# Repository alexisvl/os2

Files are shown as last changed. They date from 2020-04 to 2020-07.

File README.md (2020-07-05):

# OS-2

dope ass 90s under construction gif

This is my attempt at building an analog oscilloscope.

Bit of a self-indulgent project and I'm just posting it here so I don't hoard
it for myself. Nothing here is probably of use to anybody, and I have no plan
on making it in any way reproducible. License for all design files and
documentation is CC BY-NC-SA, note _non-commercial_. Any code is independently
licensed, typically GPL. If you want to spend a lot of money building something
mildly useful, feel free to build one.

## Specs

- At least 20 MHz bandwidth, maybe more
- Two to four channels
    - 1mV/div to 5V/div
    - AC, DC, GND coupling; 50 ohm or 1M termination
    - Switchable bandwidth limit per channel (if the overall bandwidth is high enough?)
- On-screen display for scale factors (raster scan)
- No software - ROM LUTs and GAL/PALs at most

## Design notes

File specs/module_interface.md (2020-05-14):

# OS-2 module interface

While the OS-2 does not utilize removable plugins, several system blocks are
implemented as self-contained modules. This document describes the interface
between them and the rest of the system.

## Power interface

Several power supplies are provided to modules, on the followings pins:

- GND (many pins, interspersed on connector)
- +55V - low current, analog rail
- +24V - high current, bulk unregulated rail
- +15V - medium current, quiet analog rail
- +12V - high current, general rail (relays, etc)
- +10.00V - low current (≤10mA), precise reference rail
- +5V - high current, general rali
- -15V - medium current, quiet analog rail
- -55V - low current, analog rail

## On-screen display (OSD) interface

(See also: [On-screen display](./on_screen_display.md))

The following pins go to all vertical, horizontal, and caption modules to
implement the on-screen display:

| Pin | Direction | Function |
|---|---|---|
| FIELDSELECT | to mod | Asserts when module should drive CHARn |
| POS0 – POS2 | to mod | Selects a character position (0-7) |
| CHAR0 – CHAR6 | from mod  | Open coll; drives character bits on SELECT |
| CHARINTEN | from mod  | Open coll active low; intensifies character |

From the moment FIELDSELECT or POSn changes, a module has 10µs to respond with
the next character code. When FIELDSELECT is not asserted, the module should not
drive the CHARn lines.

Because the OSD interface prefetches one character ahead of the display module,
the normal INTEN signal cannot be used to intensify the character being
requested. Use CHARINTEN instead; this is latched for use in the next cycle.

## Signal interfaces

The signal interface is a differential current-sink interface. It is biased to
a common-mode voltage by the receiver and terminated into 160 ohms differential.

Signal level is 0.5V per division, with the center of the display at (ideally)
0V. Because the display measures 10 divisions by 8 divisions, the voltage to
reach the display edges is ±2.5V (horizontally) or ±2.0V (vertically), or
±16.6mA (horizontally) or ±13.3mA (vertically) current-mode. Common-mode sink
current may be up to 30mA.

Common-mode termination voltages vary to simplify circuit implementation. They
are as follows:

- Primary SIG/TSIG signals from vertical modules terminate into +4.5V. Trigger
    level output LEVEL is included here (it behaves as an extra vertical
    channel) as is OSDV.
- Primary horizontal signals SIG, TSIG terminate into +9V, allowing them to
    be easily developed from the prior +4.5V signals.
- Display switch output SIG terminates into +9V.

An example termination circuit and transmitter for 16.6mApp. To use at 13.3mApp
with the same input voltage, change the 120 ohm gain resistor to 180 ohms. Gain
values are approximate; for applications requiring accurate gain a gain trimpot
is suggested.

```
                   |       |
                   C       C
Vcm + 0.65V ------B-------B
                   E       E
                   |       |
        Vcm --[68]-+       +-[68]-- Vcm
                   |       |      
                   |       |
                   |       |
                   |       |
                   .inputs .
                   .       .
                   backplane   
                   .       .
                   .outputs.
                   |       |
                   +-[150]-+
                   |       |
                   C       C
single:  2Vpp ----B         B---- gnd
diff:    1Vpp      E       E      1Vpp 180°
                   |       |
                   +-[120]-+
                   |       |
                 [1 k]   [1 k]
                   |       |
                 -15V    -15V
```

### Vertical module

User IO:
- BNC input with probe sense ring
- Rotary encoder to select scale multipliers, LEDs to display
- Rotary encoder to select V/div
- Vernier pot and switch
- AC-GND-DC-GND-50 slider
- Invert slider
- ADD 1+2 or 3+4 slider on odd-numbered modules

Trigger signals are buffered duplicates of the primary signals.

| Pin | Direction | Function | Mode |
|---|---|---|---|
| SIG+ | from mod  | Primary signal, +ve | Differential, +4.5Vcm |
| SIG- | from mod  | Primary signal, -ve | Differential, +4.5Vcm |
| TSIG+ | from mod  | Trigger signal, +ve | Differential, +4.5Vcm |
| TSIG- | from mod  | Trigger signal, -ve | Differential, +4.5Vcm |
| INTEN | from mod  | Logic, assert to intensify | Open-coll active low 5V |
| BLANK | from mod  | Logic, assert to blank | Open-cool active low 5V |
| ACTIVE | to mod | Asserts when displaying | 5V CMOS |

ACTIVE is asserted by the display sequencer whenever this module's output is
currently being displayed. It should gate the INTEN signal, such that this
module will not drive INTEN while other modules are active.

### Trigger module

User IO:
- BNC external trigger
- Slider to select source: INT-EXT-LINE
- Rotary encoder to select internal source: CH1-CH2-CH3-CH4-ALL, LEDs to display
- Level pot
- Level slider: rising-falling

| Pin | Direction | Function | Mode |
|---|---|---|---|
| TSIG1+ | to mod | Trigger signal, +ve | Differential, +4.5Vcm |
| TSIG1- | to mod | Trigger signal, -ve | Differential, +4.5Vcm |
| TSIG2+ | to mod | Trigger signal, +ve | Differential, +4.5Vcm |
| TSIG2- | to mod | Trigger signal, -ve | Differential, +4.5Vcm |
| TSIG3+ | to mod | Trigger signal, +ve | Differential, +4.5Vcm |
| TSIG3- | to mod | Trigger signal, -ve | Differential, +4.5Vcm |
| TSIG4+ | to mod | Trigger signal, +ve | Differential, +4.5Vcm |
| TSIG4- | to mod | Trigger signal, -ve | Differential, +4.5Vcm |
| DONE | to mod | Sweep is complete | 5V CMOS |
| SWEEP | from mod  | Sweep gate | 5V CMOS |
| INHIBIT | to mod | Blocks trigger | Open-coll active low 5V |
| LEVEL+ | from mod  | DC trigger level, +ve | Differential, +4.5Vcm |
| LEVEL- | from mod  | DC trigger level, -ve | Differential, +4.5Vcm |
| LINE | to mod | Line trigger signal | 5V CMOS |
| SEL0-2 | to mod | Pre-decode OSD select | 5V CMOS |
| LVLEN | from mod  | Trigger level auto en | 5V CMOS |

LEVEL signals use the same specifications as general signals but may be
unterminated. These are used to allow the OSD module to visualize the
trigger onscreen.

SELn lines from the OSD module are connected to the trigger to allow it to
insert trigger symbols into the relevant OSD space.

LVLEN will be driven high for a second or two whenever the level pot is moved
(perhaps also when other controls move) to flash the trigger level on screen
when the selector on the display switch module is set to AUTO.

### Horizontal/sweep module

| Pin | Direction | Function | Mode |
|---|---|---|---|
| SWEEP | to mod | Sweep gate | 5V CMOS |
| DONE | from mod  | Sweep is complete | 5V CMOS |
| CH2+ | to mod | Ch2 for X/Y mode (+ve) | Differential, +4.5Vcm unterm  |
| CH2- | to mod | Ch2 for X/Y mode (-ve) | Differential, +4.5Vcm unterm  |
| OSDH+ | to mod | Horiz OSD scan, +ve | Differential, +4.5Vcm |
| OSDH- | to mod | Horiz OSD scan, -ve | Differential, +4.5Vcm |
| SIG+ | from mod  | Primary signal, +ve | Differential, +9.0Vcm |
| SIG- | from mod  | Primary signal, -ve | Differential, +9.0Vcm |
| TSIG+ | from mod  | Secondary signal, +ve | Differential, +9.0Vcm |
| TSIG- | from mod  | Secondary signal, -ve | Differential, +9.0Vcm |

TSIG is repurposed for rear panel ramp output, if used.

CH2 is an unterminated input bussed with TSIG2 on the trigger module, used to
deliver Ch 2 for use as the horizontal axis in X/Y mode.

SWEEP asserts for the duration of the sweep, and this module will assert DONE
when the sweep terminates; the trigger module may then begin counting its
holdoff and then re-arm.

OSDSIG lines are always summed into SIG but never into TSIG. When idle, the OSD
module will leave them at zero.

### Display sequencer module

User controls:
- Enable Ch1/Ch2/Ch3/Ch4
- Alt/Chop
- OSD on/off
- Trigger level display slider: OFF-AUTO-ON

| Pin | Direction | Function | Mode |
|---|---|---|---|
| SIG1+ | to mod | Signal input, +ve | Differential, +4.5Vcm |
| SIG1- | to mod | Signal input, -ve | Differential, +4.5Vcm |
| SIG2+ | to mod | Signal input, +ve | Differential, +4.5Vcm |
| SIG2- | to mod | Signal input, -ve | Differential, +4.5Vcm |
| SIG3+ | to mod | Signal input, +ve | Differential, +4.5Vcm |
| SIG3- | to mod | Signal input, -ve | Differential, +4.5Vcm |
| SIG4+ | to mod | Signal input, +ve | Differential, +4.5Vcm |
| SIG4- | to mod | Signal input, -ve | Differential, +4.5Vcm |
| OSDV+ | to mod | OSD scan input, +ve | Differential, +4.5Vcm |
| OSDV- | to mod | OSD scan input, -ve | Differential, +4.5Vcm |
| LEVEL+ | to mod | Trigger level input, +ve | Differential, +4.5Vcm |
| LEVEL- | to mod | Trigger level input, -ve | Differential, +4.5Vcm |
| OSDSEL | from mod  | Asserts when OSD selected | 5V CMOS |
| OSDDONE | to mod | Asserted when OSD completes | 5V CMOS |
| SWEEP | to mod | Sweep gate | 5V CMOS |
| DONE | to mod | Sweep is done | 5V CMOS |
| INHIBIT | from mod  | Trigger inhibit | Open-coll active low 5V |
| SIG+ | from mod  | Vertical signal out, +ve | Differential, +9.0Vcm |
| SIG- | from mod  | Vertical signal out, -ve | Differential, +9.0Vcm |
| TSIG+ | from mod  | Secondary signal out, +ve | Differential, +9.0Vcm |
| TSIG- | from mod  | Secondary signal out, -ve | Differential, +9.0Vcm |
| ADD12 | to mod | Asserts to sum ch1+ch2 | 5V CMOS |
| ADD34 | to mod | Asserts to sum ch3+ch4 | 5V CMOS |
| ALTINTEN  | from mod  | Selects alternate (OSD) inten | 5V CMOS |
| LVLEN | to mod | Trigger level auto enable | 5V CMOS |
| ACTIVE2-0 | from mod  | Active module indicators | 5V CMOS

LEVEL is not a critical signal; it should be routed on two of the SSn lines in the
general pinout.

ACTIVEn is decoded into a one-hot signal on the backplane. It indicates which of
the modules is currently being displayed, if any.

### OSD module

Rear-facing module with no user IOs.

| Pin | Direction | Function | Mode |
|---|---|---|---|
| CHAR0-5 | to mod | Character bus | Open-coll active low 5V |
| POS0-2 | from mod  | Position select bus | 5V CMOS |
| SEL0-2 | from mod  | Source enable lines | 5V CMOS |
| OSDSEL | to mod | Asserted to start OSD scan | 5V CMOS |
| OSDDONE | from mod  | Asserts when finished | 5V CMOS |
| HSCAN+ | from mod  | Horizontal scan, +ve | Differential, +4.5Vcm |
| HSCAN- | from mod  | Horizontal scan, -ve | Differential, +4.5Vcm |
| VSCAN+ | from mod  | Vertical scan, +ve | Differential, +4.5Vcm |
| VSCAN+ | from mod  | Vertical scan, -ve | Differential, +4.5Vcm |
| BEAMINHIB | from mod  | Asserts to inhibit beam | Open-coll active low 5V |

SELn are binary outputs; these are decoded to individual enable lines on the
backplane.

### Deflection amplifier module

User IO:
    - BNC jack with 1V/div output

| Pin | Direction | Function | Mode |
|---|---|---|---|
| SIG+ | to mod | Signal to display | Differential, +9.0Vcm |
| SIG- | to mod | Signal to display | Differential, +9.0Vcm |

### Cathode control module

Front-facing module with controls:

- Brightness, main
- Brightness, OSD
- Focus
- Astig
- Rotation

| Pin | Direction | Function | Mode |
|---|---|---|---|
| INTEN | to mod | Asserts to intensify beam | Open-coll active low 5V |
| INHIB | to mod | Inhibits beam (overrides INTEN) | Open-coll active low 5V |
| ALTINTEN  | to mod | Selects alternate (OSD) intensity | 5V CMOS

# General pinout

The same pinout is allocated different variant IOs depending on the module.

| Pin (C) | Function | Pin (B) | Function | Pin (A) | Function |
|---|---|---|---|---|---|
| C1 | g | B1 | g | A1 | g |
| C2 | SIG+ | B2 | g | A2 | TSIG+ |
| C3 | SIG- | B3 | g | A3 | TSIG- |
| C4 | g | B4 | g | A4 | g |
| C5 | IN1+ | B5 | g | A5 | SS0 |
| C6 | IN1- | B6 | g | A6 | SS1 |
| C7 | g | B7 | IN2+ | A7 | g |
| C8 | g | B8 | IN2- | A8 | g |
| C9 | IN3+ | B9 | g | A9 | SS2 |
| C10 | IN3- | B10 | g | A10 | SS3 |
| C11 | g | B11 | IN4+ | A11 | g |
| C12 | g | B12 | IN4- | A12 | g |
| C13 | IN5+ | B13 | g | A13 | SS4 |
| C14 | IN5- | B14 | g | A14 | SS5 |
| C15 | g | B15 | g | A15 | g |
| C16 | SA0 | B16 | SA1 | A16 | SA2 |
| C17 | SA3 | B17 | SA4 | A17 | g |
| C18 | SA5 | B18 | SA6 | A18 | SA7 |
| C19 | g | B19 | SA8 | A19 | SA9 |
| C20 | SA10 | B20 | g | A20 | SA11 |
| C21 | SA12 | B21 | SA13 | A21 | SA14 |
| C22 | SA15 | B22 | CHAR0 | A22 | CHAR1 |
| C23 | CHAR2 | B23 | CHAR3 | A23 | CHAR4 |
| C24 | CHAR5 | B24 | CHAR6 | A24 | CHARINTEN |
| C25 | POS0 | B25 | POS1 | A25 | POS2 |
| C26 | FIELDSELECT | B26 | g | A26 | +24V |
| C27 | g | B27 | +55V | A27 | +24V |
| C28 | g | B28 | +15V | A28 | +12V |
| C29 | +10.00V | B29 | g | A29 | +12V |
| C30 | g | B30 | g | A30 | +5V |
| C31 | -55V | B31 | -15V | A31 | +5V |
| C32 | g | B32 | g | A32 | g |

- SSn lines are "sweep synchronous". They are located in places where toggling
during a sweep could impose noise on the display, so they should only toggle
between sweeps. Example signals to allocate here are SWEEP, DONE.

- SAn lines are "sweep asynchronous". They are separated well from the analog
signal pins, and may toggle during sweep. These are generally used for all logic
signals not otherwise allocated to SSn.

- POSn, CHARn are the OSD IO lines bussed to all modules.

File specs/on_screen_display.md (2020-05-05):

# OS-2 on-screen display

## Display layout

The display has several areas where on-screen display content is overlayed with
the primary signal display:

```
VERT1   VERT2   VERT3   VERT4

>------- trig  level -------<

DESC1DESC2DESC3         HORIZ
```

All text fields are eight spaces long.

- `VERT1` through `VERT4`: each is "owned" by a different vertical channel
module. It typically displays a scale factor (like "5V") as well as one
of a few icons (a sine wave sign to indicate AC coupling, a ground symbol
for ground coupling, a Tek-style halfwidth BW for bandwidth limiting,
trigger indicators, an ohm sign for 50-ohm termination, an alert sign
for termination overheat or other critical conditions, and a transient
"IDENT" indication when a probe identifier is activated).

- `DESC1` to `DESC3` are arranged so they flow together into a single field,
and exist so that an optional captioning plugin may be used to write user-
specified labels onto the display.

- `HORIZ` displays a horizontal scale factor (like "50µs") and alternative
trigger source icons ("AU" for auto triggering, "LN" for line triggering)
that are not associated with a vertical channel.

- "Trig level" is a dashed line that can be optionally drawn across the display
at the selected trigger point. (Suggested dashed-line implementation: 555
timer, astable, reset line driven by sweep gate. This will reset it on every
sweep so the dashes line up)

All vertical channels should emit a space (0x3F, no lines asserted) for
position 0. The trigger module will insert trigger level symbols on the
relevant channel during the scan sequence.

## Character encoding

The OS-2 character encoding is six bits wide, and is defined as follows:

| Code  | Character |
|---|---|
| 0x00  | 0 |
| 0x01  | 1 |
| 0x02  | 2 |
| 0x03  | 3 |
| 0x04  | 4 |
| 0x05  | 5 |
| 0x06  | 6 |
| 0x07  | 7 |
| 0x08  | 8 |
| 0x09  | 9 |
| 0x0A  | . |
| 0x0B  | < |
| 0x0C  | > |
| 0x0D  | / |
| 0x0E  | - |
| 0x0F  | + |
| 0x10  | ∿ (sine wave) |
| 0x11  | Ω |
| 0x12  | ground symbol |
| 0x13  | BW (Tek style, combined single width) |
| 0x14  | LN (a la BW, for "LINE") |
| 0x15  | AU (a la BW, for "AUTO") |
| 0x16  | rising edge |
| 0x17  | falling edge |
| 0x18  | both edges |
| 0x19  | alert sign |
| 0x1A  | A |
| 0x1B  | B |
| 0x1C  | C |
| 0x1D  | D |
| 0x1E  | E |
| 0x1F  | F |
| 0x20  | G |
| 0x21  | H |
| 0x22  | I |
| 0x23  | J |
| 0x24  | K |
| 0x25  | L |
| 0x26  | M |
| 0x27  | N |
| 0x28  | O |
| 0x29  | P |
| 0x2A  | Q |
| 0x2B  | R |
| 0x2C  | S |
| 0x2D  | T |
| 0x2E  | U |
| 0x2F  | V |
| 0x30  | W |
| 0x31  | X |
| 0x32  | Y |
| 0x33  | Z |
| 0x34  | k |
| 0x35  | m |
| 0x36  | µ |
| 0x37  | n |
| 0x38  | p |
| 0x39  | s |
| 0x3A  | ° |
| 0x3B  | ? |
| 0x3C  | ♥ |
| 0x3D  | dither block |
| 0x3E  | full block |
| 0x3F  | space |

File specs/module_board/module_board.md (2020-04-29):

# Module board design

The module board format is inspired by (but not directly compatible with)
Eurocard. Overall dimensions are 160 by 100 mm, with a 64-pin DIN 41612
connector at the rear end, and a faceplate at the front end for connectors
and printed legends. The PCB layout file accompanying this document shall
serve as the specification for the format.

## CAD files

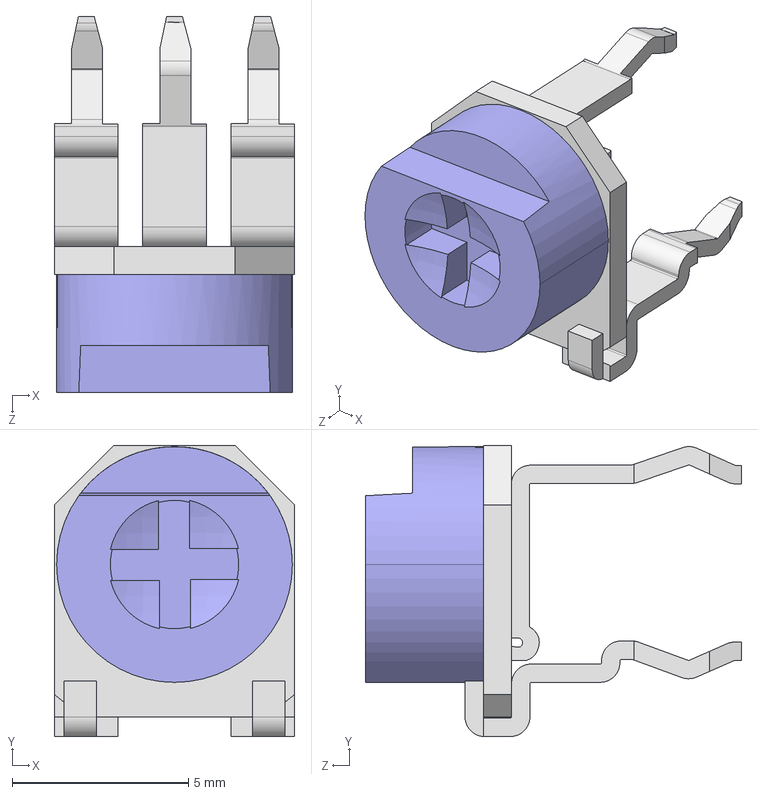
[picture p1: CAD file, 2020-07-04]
sch/gfx/User Library-Trimmer, 3306F-1.STEP
6.81 x 8.25 x 10.7 mm

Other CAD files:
mech/chassis.dxf

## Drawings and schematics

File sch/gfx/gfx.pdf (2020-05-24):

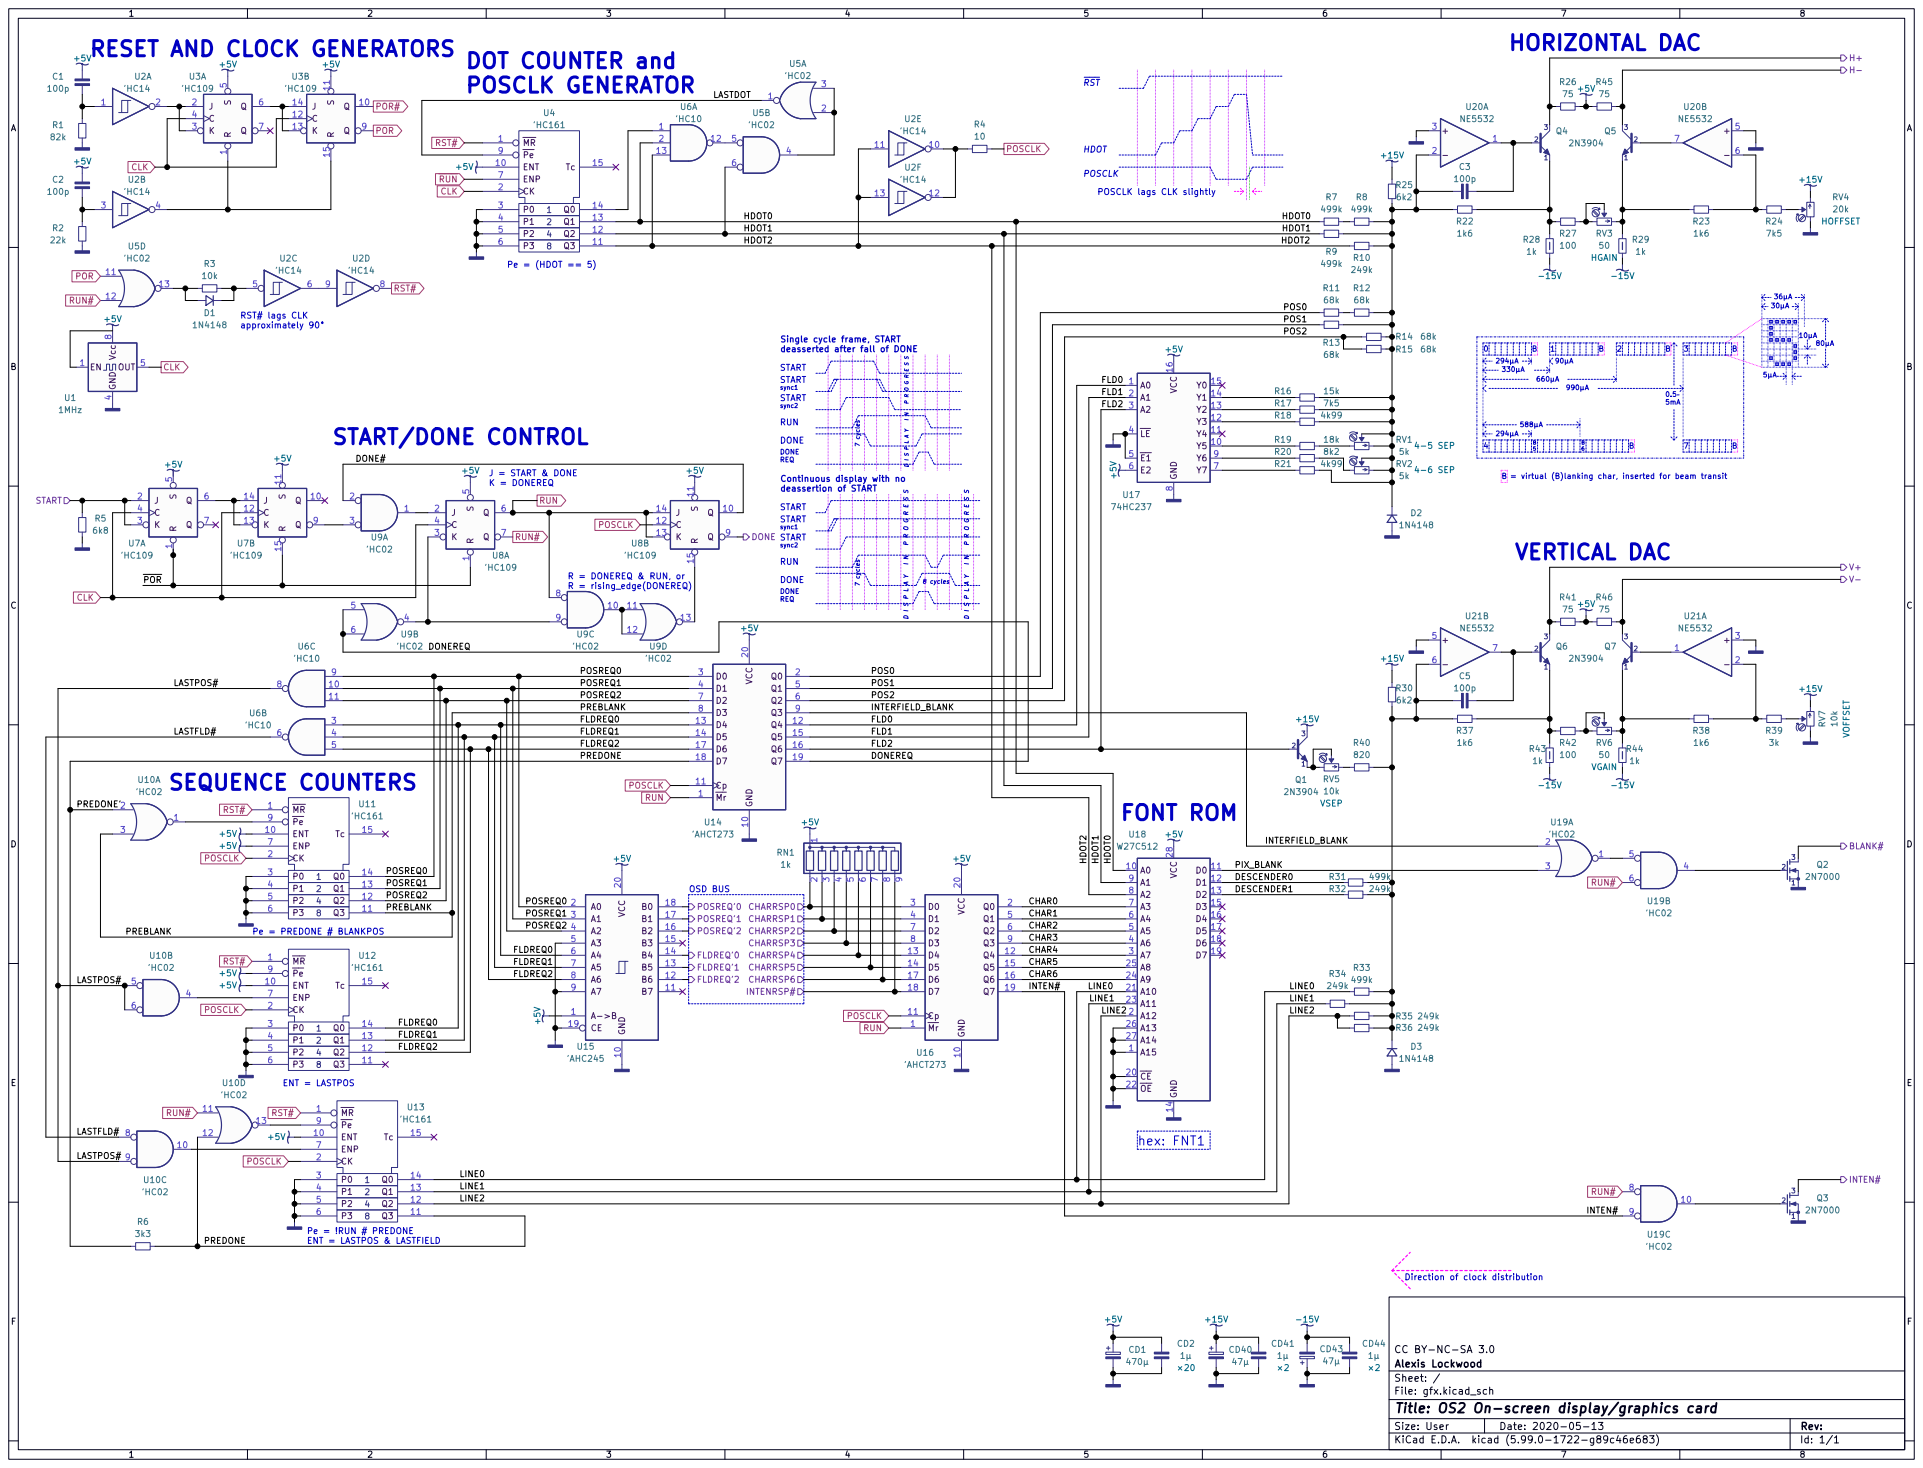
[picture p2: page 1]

5mA Pe = PREDONE # BLANKPOS RESET AND CLOCK GENERATORS DOT COUNTER and

POSCLK lags CLK slightly

Single cycle frame, START
80µA START
sync1 START

294µA R = DONEREQ & RUN, or R = rising_edge(DONEREQ)

sync2 DONE
DONE REQ Continuous display with no

Direction of clock distribution

File: gfx.kicad_sch Sheet: / Alexis Lockwood CC BY-NC-SA 3.0

Id: 1/1 Title: OS2 On-screen display/graphics card

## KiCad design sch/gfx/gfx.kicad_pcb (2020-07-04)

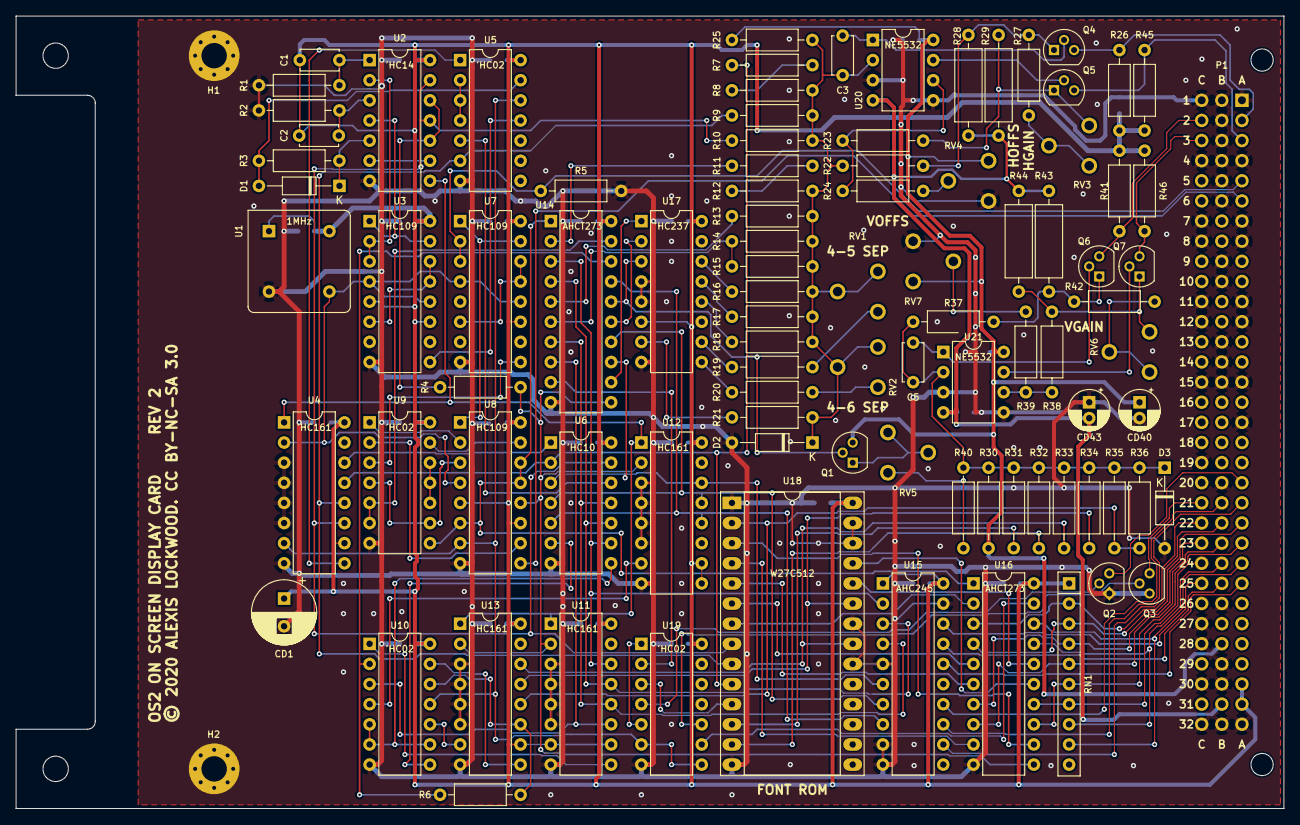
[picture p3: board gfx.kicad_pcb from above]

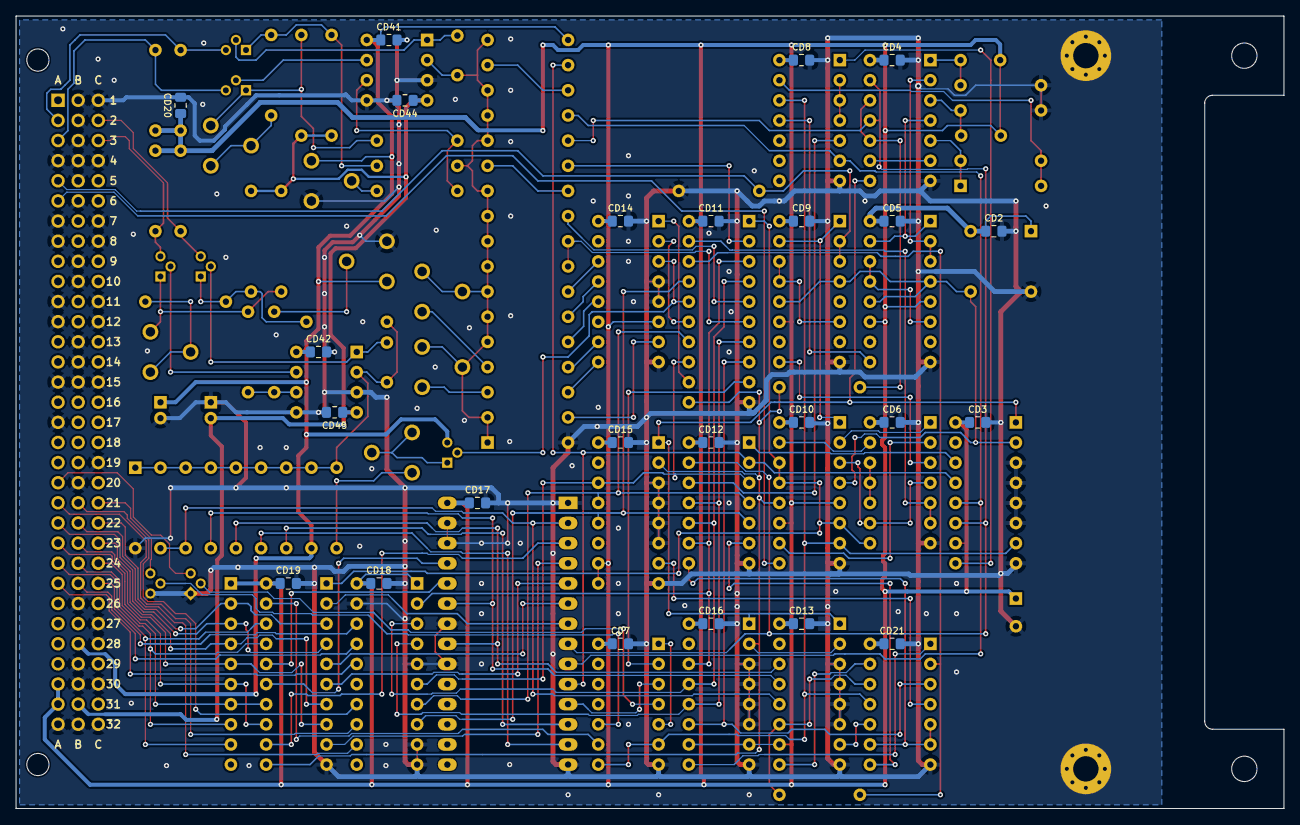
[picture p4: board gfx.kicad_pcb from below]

Board: 2 copper layers, 160.0 x 100.0 mm, 119 parts (24 on the bottom side), 124 nets.

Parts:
C1, C2, C3, C5: 100p; C_Disc_D4.7mm_W2.5mm_P5.00mm
CD1: 470µ; CP_Radial_D8.0mm_P3.50mm
CD2, CD3, CD4, CD5, CD6, CD7, CD8, CD9, CD10, CD11, CD12, CD13, CD14, CD15, CD16, CD17, CD18, CD19, CD20, CD21, CD41, CD42, CD44, CD45: 1µ; C_0805_2012Metric_Pad1.15x1.40mm_HandSolder
CD40, CD43: 47µ; CP_Radial_D5.0mm_P2.00mm
D1, D2, D3: 1N4148; D_DO-35_SOD27_P10.16mm_Horizontal
H1, H2: HOLE; MountingHole_3.2mm_M3_Pad_Via
P1: DIN41612_M_3x32; DIN41612_B_3x32_Horizontal
Q1, Q4, Q5, Q6, Q7: 2N3904; TO-92
Q2, Q3: 2N7000; TO-92
R1: 82k; R_Axial_DIN0207_L6.3mm_D2.5mm_P10.16mm_Horizontal
R2: 22k; R_Axial_DIN0207_L6.3mm_D2.5mm_P10.16mm_Horizontal
R3: 10k; R_Axial_DIN0207_L6.3mm_D2.5mm_P10.16mm_Horizontal
R4: 10; R_Axial_DIN0207_L6.3mm_D2.5mm_P10.16mm_Horizontal
R5: 6k8; R_Axial_DIN0207_L6.3mm_D2.5mm_P10.16mm_Horizontal
R6: 3k3; R_Axial_DIN0207_L6.3mm_D2.5mm_P10.16mm_Horizontal
R7, R8, R9, R31, R33: 499k; R_Axial_DIN0207_L6.3mm_D2.5mm_P10.16mm_Horizontal
R10, R32, R34, R35, R36: 249k; R_Axial_DIN0207_L6.3mm_D2.5mm_P10.16mm_Horizontal
R11, R12, R13, R14, R15: 68k; R_Axial_DIN0207_L6.3mm_D2.5mm_P10.16mm_Horizontal
R16: 15k; R_Axial_DIN0207_L6.3mm_D2.5mm_P10.16mm_Horizontal
R17, R24: 7k5; R_Axial_DIN0207_L6.3mm_D2.5mm_P10.16mm_Horizontal
R18, R21: 4k99; R_Axial_DIN0207_L6.3mm_D2.5mm_P10.16mm_Horizontal
R19: 18k; R_Axial_DIN0207_L6.3mm_D2.5mm_P10.16mm_Horizontal
R20: 8k2; R_Axial_DIN0207_L6.3mm_D2.5mm_P10.16mm_Horizontal
R22, R23, R37, R38: 1k6; R_Axial_DIN0207_L6.3mm_D2.5mm_P10.16mm_Horizontal
R25, R30: 6k2; R_Axial_DIN0207_L6.3mm_D2.5mm_P10.16mm_Horizontal
R26, R41, R45, R46: 75; R_Axial_DIN0207_L6.3mm_D2.5mm_P10.16mm_Horizontal
R27, R42: 100; R_Axial_DIN0207_L6.3mm_D2.5mm_P10.16mm_Horizontal
R28, R29, R43, R44: 1k; R_Axial_DIN0309_L9.0mm_D3.2mm_P12.70mm_Horizontal
R39: 3k; R_Axial_DIN0207_L6.3mm_D2.5mm_P10.16mm_Horizontal
R40: 820; R_Axial_DIN0207_L6.3mm_D2.5mm_P10.16mm_Horizontal
RN1: 1k; R_Array_SIP10
RV1, RV2: 5k; stock_pot
RV3, RV6: 50; stock_pot
RV4: 20k; stock_pot
RV5, RV7: 10k; stock_pot
U1: 1MHz; Oscillator_DIP-8
U2: 'HC14; DIP-14_W7.62mm
U3, U7, U8: 'HC109; DIP-16_W7.62mm
U4, U11, U12, U13: 'HC161; DIP-16_W7.62mm
U5, U9, U10, U19: 'HC02; DIP-14_W7.62mm
U6: 'HC10; DIP-14_W7.62mm
U14, U16: 'AHCT273; DIP-20_W7.62mm
U15: 'AHC245; DIP-20_W7.62mm
U17: 'HC237; DIP-16_W7.62mm
U18: W27C512; DIP-28_W15.24mm_Socket_LongPads
U20, U21: NE5532; DIP-8_W7.62mm

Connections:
+15V: CD40.1, CD41.1, CD42.1, P1.B28, Q1.3 (C), R25.2, R30.2, RV4.3, RV7.3, U20.8 (V+), U21.8 (V+)
-15V: CD43.2, CD44.1, CD45.1, P1.B31, R28.1, R29.1, R43.1, R44.1, U20.4 (V-), U21.4 (V-)
/CHAR0: U16.2 (Q0), U18.7 (A3)
/CHAR1: U16.5 (Q1), U18.6 (A4)
/CHAR2: U16.6 (Q2), U18.5 (A5)
/CHAR3: U16.9 (Q3), U18.4 (A6)
/CHAR4: U16.12 (Q4), U18.3 (A7)
/CHAR5: U16.15 (Q5), U18.25 (A8)
/CHAR6: U16.16 (Q6), U18.24 (A9)
/DESCENDER0: R31.2, U18.12 (D1)
/DESCENDER1: R32.2, U18.13 (D2)
/DONE#: U8.10 (Q), U9.2
/DONEREQ: U9.5, U9.6, U14.19 (Q7)
/FLD0: U14.12 (Q4), U17.1 (A0)
/FLD1: U14.15 (Q5), U17.2 (A1)
/FLD2: Q1.2 (B), U14.16 (Q6), U17.3 (A2)
/FLDREQ0: U6.3, U12.14 (Q0), U14.13 (D4), U15.6 (A4)
/FLDREQ1: U6.4, U12.13 (Q1), U14.14 (D5), U15.7 (A5)
/FLDREQ2: U6.5, U12.12 (Q2), U14.17 (D6), U15.8 (A6)
/HDOT0: R7.2, U4.13 (Q1), U6.2, U18.10 (A0)
/HDOT1: R9.2, U4.12 (Q2), U5.6, U18.9 (A1)
/HDOT2: R10.2, U2.11, U2.13, U4.11 (Q3), U6.13, U18.8 (A2)
/INTEN#: U16.19 (Q7), U19.9
/INTERFIELD_BLANK: U14.9 (Q3), U19.2
/LASTDOT: U4.9 (~Pe), U5.1
/LASTFLD#: U6.6, U10.8
/LASTPOS#: U6.8, U10.5, U10.6, U10.9
/LINE0: R33.2, U13.14 (Q0), U18.21 (A10)
/LINE1: R34.2, U13.13 (Q1), U18.23 (A11)
/LINE2: R35.2, R36.2, U13.12 (Q2), U18.2 (A12)
/PIX_BLANK: U18.11 (D0), U19.3
/POS0: R11.2, U14.2 (Q0)
/POS1: R13.2, U14.5 (Q1)
/POS2: R14.2, R15.2, U14.6 (Q2)
/POSREQ0: U6.9, U11.14 (Q0), U14.3 (D0), U15.2 (A0)
/POSREQ1: U6.10, U11.13 (Q1), U14.4 (D1), U15.3 (A1)
/POSREQ2: U6.11, U11.12 (Q2), U14.7 (D2), U15.4 (A2)
/PREBLANK: U10.3, U11.11 (Q3), U14.8 (D3)
/PREDONE: R6.2, U10.12, U13.11 (Q3)
/PREDONE': R6.1, U10.2, U14.18 (D7)
/~POR: U7.1 (R), U7.15 (R), U8.1 (R)
A2: P1.A2, Q4.3 (C), R26.1
A3: P1.A3, Q5.3 (C), R45.2
A5: P1.A5, R5.2, U7.2 (J), U7.3 (K)
A6: P1.A6, U8.9 (Q)
A20: P1.A20, Q2.3 (D)
A21: P1.A21, U15.13 (B5)
A22: P1.A22, RN1.3 (R2), U16.4 (D1)
A23: P1.A23, RN1.6 (R5), U16.13 (D4)
A24: P1.A24, RN1.9 (R8), U16.18 (D7)
A25: P1.A25, U15.16 (B2)
B21: P1.B21, U15.14 (B4)
B22: P1.B22, RN1.2 (R1), U16.3 (D0)
B23: P1.B23, RN1.5 (R4), U16.8 (D3)
B24: P1.B24, RN1.8 (R7), U16.17 (D6)
B25: P1.B25, U15.17 (B1)
C2: P1.C2, Q6.3 (C), R41.1
C3: P1.C3, Q7.3 (C), R46.2
C21: P1.C21, Q3.3 (D)
C22: P1.C22, U15.12 (B6)
C23: P1.C23, RN1.4 (R3), U16.7 (D2)
C24: P1.C24, RN1.7 (R6), U16.14 (D5)
C25: P1.C25, U15.18 (B0)
CLK: U1.5 (OUT), U3.4 (C), U3.12 (C), U4.2 (CK), U7.4 (C), U7.12 (C), U8.4 (C)
GND: CD1.2, CD2.2, CD3.2, CD4.2, CD5.2, CD6.2, CD7.2, CD8.2, CD9.2, CD10.2, CD11.2, CD12.2, CD13.2, CD14.2, CD15.2, CD16.2, CD17.2, CD18.2, CD19.2, CD20.2, CD21.2, CD40.2, CD41.2, CD42.2, CD43.1, CD44.2, CD45.2, D2.2 (A), D3.2 (A), H1.1, H2.1, P1.A1, P1.A4, P1.A7, P1.A8, P1.A11, P1.A12, P1.A15, P1.A17, P1.A32, P1.B1, P1.B2, P1.B3, P1.B4, P1.B5, P1.B6, P1.B9, P1.B10, P1.B13, P1.B14, P1.B15, P1.B20, P1.B26, P1.B29, P1.B30, P1.B32, P1.C1, P1.C4, P1.C7, P1.C8, P1.C11, P1.C12, P1.C15, P1.C19, P1.C27, P1.C28, P1.C30, P1.C32, Q2.1 (S), Q3.1 (S), R1.2, R2.2, R5.1, RV4.1, RV7.1, U1.4 (GND), U2.7 (GND), U3.8 (GND), U4.3 (P0), U4.4 (P1), U4.5 (P2), U4.6 (P3), U4.8 (GND), U5.7 (GND), U6.7 (GND), U7.8 (GND), U8.8 (GND), U9.7 (GND), U10.7 (GND), U11.3 (P0), U11.4 (P1), U11.5 (P2), U11.6 (P3), U11.8 (GND), U12.3 (P0), U12.4 (P1), U12.5 (P2), U12.6 (P3), U12.8 (GND), U13.3 (P0), U13.4 (P1), U13.5 (P2), U13.6 (P3), U13.8 (GND), U14.10 (GND), U15.5 (A3), U15.9 (A7), U15.10 (GND), U15.19 (CE), U16.10 (GND), U17.4 (~LE), U17.5 (~E1), U17.8 (GND), U18.1 (A15), U18.14 (GND), U18.20 (~CE), U18.22 (~OE), U18.26 (A13), U18.27 (A14), U19.7 (GND), U20.3 (+), U20.5 (+), U21.3 (+), U21.5 (+)
unnamed: C1.2, R1.1, U2.1
unnamed: C2.2, R2.1, U2.3
unnamed: C3.1, D2.1 (K), R8.1, R9.1, R10.1, R12.1, R13.1, R14.1, R15.1, R16.1, R17.1, R18.1, R21.1, R22.1, R25.1, RV1.2, RV1.3, RV2.2, RV2.3, U20.2 (-)
unnamed: C3.2, Q4.2 (B), U20.1
unnamed: C5.1, D3.1 (K), R30.1, R31.1, R32.1, R33.1, R34.1, R35.1, R36.1, R37.1, R40.1, U21.2 (-)
unnamed: C5.2, Q6.2 (B), U21.1
unnamed: D1.1 (K), R3.2, U2.5
unnamed: D1.2 (A), R3.1, U5.13
unnamed: Q1.1 (E), RV5.1, RV5.2
unnamed: Q2.2 (G), U19.4
unnamed: Q3.2 (G), U19.10
unnamed: Q4.1 (E), R22.2, R27.1, R28.2
unnamed: Q5.1 (E), R23.1, R29.2, RV3.3
unnamed: Q5.2 (B), U20.7
unnamed: Q6.1 (E), R37.2, R42.1, R43.2
unnamed: Q7.1 (E), R38.1, R44.2, RV6.3
unnamed: Q7.2 (B), U21.7
unnamed: R4.1, U2.10, U2.12
unnamed: R7.1, R8.2
unnamed: R11.1, R12.2
unnamed: R16.2, U17.14 (Y1)
unnamed: R17.2, U17.13 (Y2)
unnamed: R18.2, U17.12 (Y3)
unnamed: R19.1, RV1.1
unnamed: R19.2, U17.10 (Y5)
unnamed: R20.1, RV2.1
unnamed: R20.2, U17.9 (Y6)
unnamed: R21.2, U17.7 (Y7)
unnamed: R23.2, R24.1, U20.6 (-)
unnamed: R24.2, RV4.2
unnamed: R27.2, RV3.1, RV3.2
unnamed: R38.2, R39.1, U21.6 (-)
unnamed: R39.2, RV7.2
unnamed: R40.2, RV5.3
unnamed: R42.2, RV6.1, RV6.2
unnamed: U2.2, U3.2 (J), U3.3 (K)
unnamed: U2.4, U3.1 (R), U3.15 (R)
unnamed: U2.6, U2.9
unnamed: U3.6 (Q), U3.13 (K), U3.14 (J)
unnamed: U4.14 (Q0), U6.1
unnamed: U5.2, U5.3, U5.4
unnamed: U5.5, U6.12
unnamed: U7.9 (Q), U9.3
unnamed: U7.6 (Q), U7.13 (K), U7.14 (J)
unnamed: U8.2 (J), U9.1
unnamed: U8.3 (K), U9.4, U9.9
unnamed: U8.15 (R), U9.13
unnamed: U9.10, U9.11, U9.12
unnamed: U10.1, U11.9 (~Pe)
unnamed: U10.4, U12.7 (ENP)
unnamed: U10.10, U13.7 (ENP)
unnamed: U10.13, U13.9 (~Pe)
unnamed: U19.1, U19.5
POR: U3.9 (Q), U5.11
POSCLK: R4.2, U8.12 (C), U11.2 (CK), U12.2 (CK), U13.2 (CK), U14.11 (Cp), U16.11 (Cp)
RST#: U2.8, U4.1 (~MR), U11.1 (~MR), U12.1 (~MR), U13.1 (~MR)
RUN: U8.6 (Q), U8.13 (K), U8.14 (J), U9.8, U14.1 (~Mr), U16.1 (~Mr)
RUN#: U4.7 (ENP), U5.12, U8.7 (Q), U10.11, U19.6, U19.8
VCC: C1.1, C2.1, CD1.1, CD2.1, CD3.1, CD4.1, CD5.1, CD6.1, CD7.1, CD8.1, CD9.1, CD10.1, CD11.1, CD12.1, CD13.1, CD14.1, CD15.1, CD16.1, CD17.1, CD18.1, CD19.1, CD20.1, CD21.1, P1.A30, P1.A31, R26.2, R41.2, R45.1, R46.1, RN1.1 (common), U1.1 (EN), U1.8 (Vcc), U2.14 (VCC), U3.5 (S), U3.11 (S), U3.16 (VCC), U4.10 (ENT), U4.16 (VCC), U5.14 (VCC), U6.14 (VCC), U7.11 (S), U7.16 (VCC), U8.5 (S), U8.11 (S), U8.16 (VCC), U9.14 (VCC), U10.14 (VCC), U11.7 (ENP), U11.10 (ENT), U11.16 (VCC), U12.9 (~Pe), U12.10 (ENT), U12.16 (VCC), U13.10 (ENT), U13.16 (VCC), U14.20 (VCC), U15.1 (A->B), U15.20 (VCC), U16.20 (VCC), U17.6 (E2), U17.16 (VCC), U18.28 (VCC), U19.14 (VCC)

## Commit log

2020-04-29 Add some interface and protoboard stuff
    [module_board.kicad_pcb]
2020-05-05 commit some work, soz for shit commit msgs
    [gfx.kicad_pcb, gfx.kicad_sch, gfx.sch]
2020-05-08 schematic cleanups
    [gfx.kicad_sch]
2020-05-14 Work in progress, not well organized, sorry
    [.kicad_sch, .kicad_sch.kicad_sch, gfx.kicad_sch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]
2020-05-24 blah blah
    [chassis.dxf, gfx.kicad_pcb, gfx.kicad_sch]
2020-06-30 gfx board, pcb version
    [gfx-B_Cu.gbl, gfx-B_Mask.gbs, gfx-B_SilkS.gbo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]
2020-07-04 gfx: sch adjustments and 3d models
    [User Library-Trimmer, 3306F-1.STEP, gfx.kicad_pcb, gfx.kicad_sch]

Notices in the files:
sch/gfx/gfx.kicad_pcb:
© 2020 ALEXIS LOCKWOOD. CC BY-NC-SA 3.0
